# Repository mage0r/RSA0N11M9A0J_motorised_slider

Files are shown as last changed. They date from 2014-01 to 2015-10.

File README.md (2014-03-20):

RSA0N11M9A0J_motorised_slider
=============

This project drives a model RSA0N11M9A0J motorised slider using a common L9110 H-Bridge driver.

It also allows using the built in capacitive sensor to prevent the motor from fighting manual movement.

There has three sections, a kicad circuit diagram, an arduino sketch using the capacitive touch library and lastly a few photos of it in action.

The specifications for the slider are available at (http://www.alps.com/WebObjects/catalog.woa/E/HTML/Potentiometer/SlidePotentiometers/RSN1M/RSA0N11M9A0J.html).  These sliders were salvaged from a Yamaha M7 Audio Mixer (http://www.yamahaproaudio.com/global/en/products/mixers/m7cl/index.jsp) while it was being refurbished.

There are two sketches in the arduino directory.  One for the attiny controller, another one with a basic i2c master for controlling the slaves.  Each sketch includes a list of required libraries.

Improvements and changes cheerfully accepted.

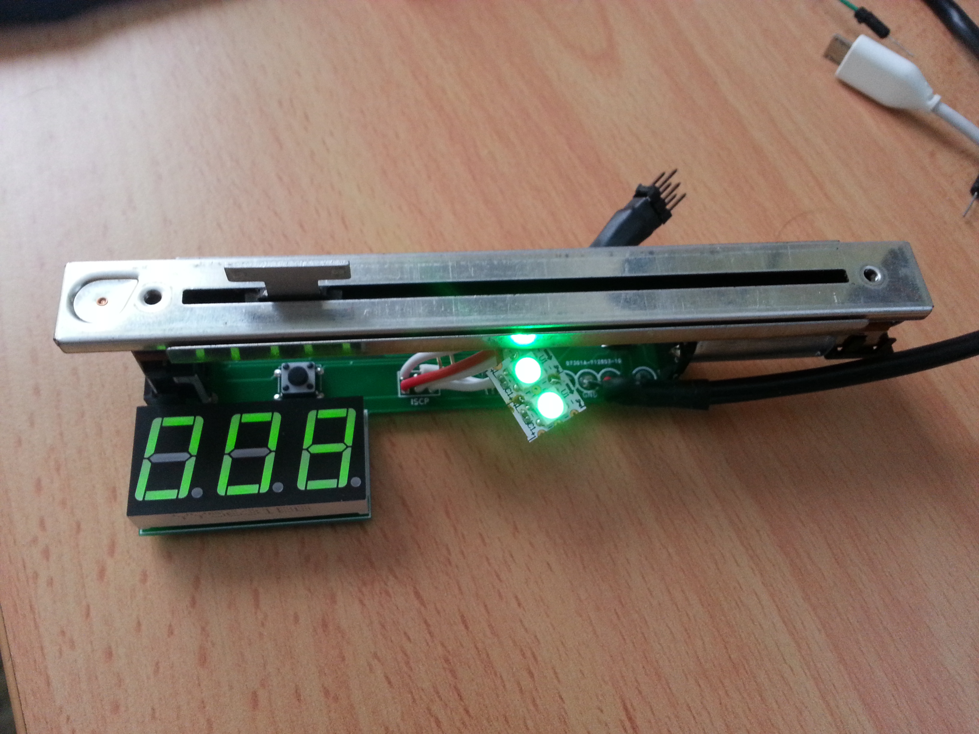
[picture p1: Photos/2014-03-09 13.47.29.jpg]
RSA0N11M9A0J_motorised_slider


(http://youtu.be/SSg5tWOZ5IY "ATtiny Slider Driver - Version 2")

(http://youtu.be/dVUSyDtoAqI "ATtiny 84 Motorised Slider - Version 3 ")

CREDITS
------------
This board was designed by John Spencer - john.spencer.9000@gmail.com - https://github.com/mage0r

SPECIAL THANKS
------------
To the creators and maintainers of the KiCAD open-source EDA suite.

To the HackMelbourne (CCHS, http://hackmelbourne.org) community of Melbourne, Australia.

To all other open-source developers whose countless hours supported every other aspect of this design.

To Andy Gelme for feature creeping an attiny in the design.

Extra thanks to Bob Powers (@rdpowers) because I copied his README.md almost verbatim...

DISTRIBUTION
------------
The specific terms of distribution of this project are governed by the
license referenced below. Please contact the copyright owner if you wish to modify the board for distribution. Please utilize this design for personal or research projects. Please acknowledge all contributors.

LICENSE
-------
Licensed under the TAPR Open Hardware License (www.tapr.org/OHL).
The "license" sub-folder also contains a copy of this license in plain text format.

Copyright John Spencer 2014
john.spencer.9000@gmail.com

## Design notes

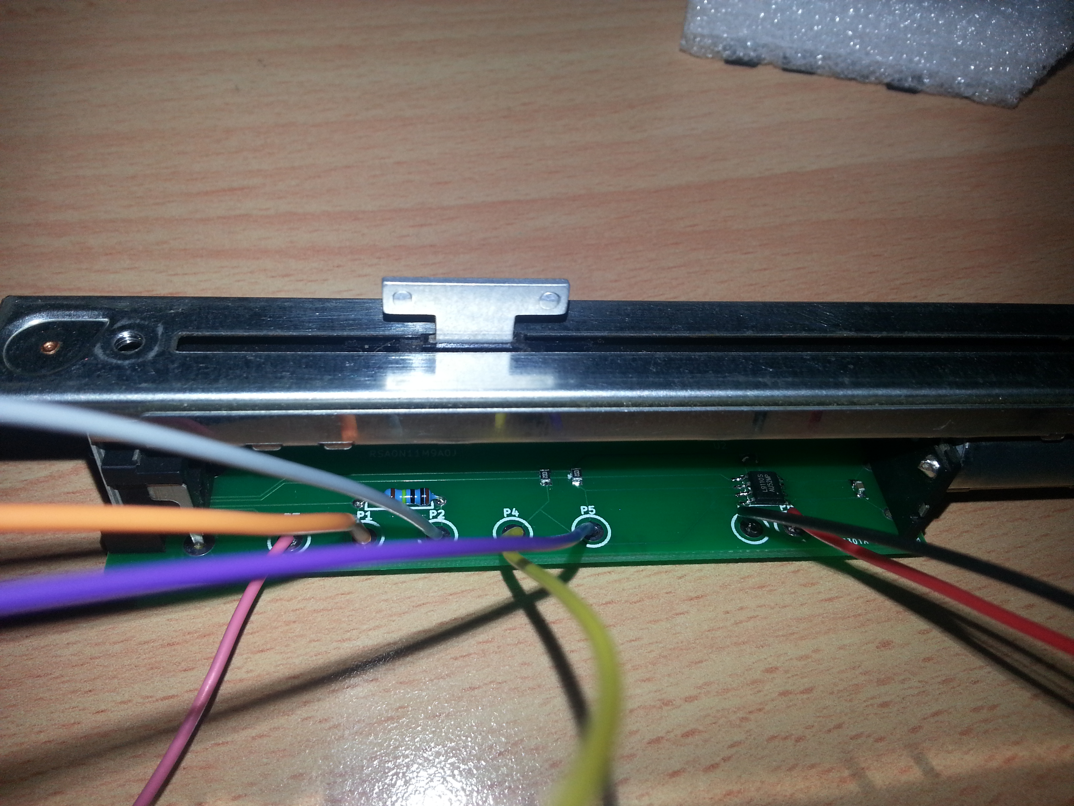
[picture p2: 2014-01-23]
Photos/2014-01-23 20.13.57.jpg

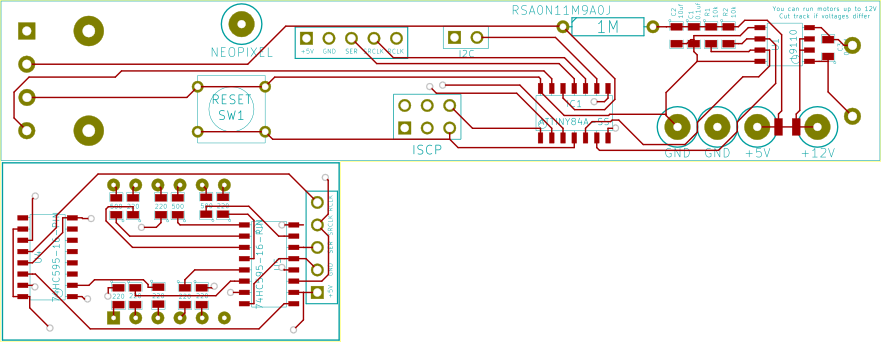
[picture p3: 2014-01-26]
Photos/slider_driver-front.png

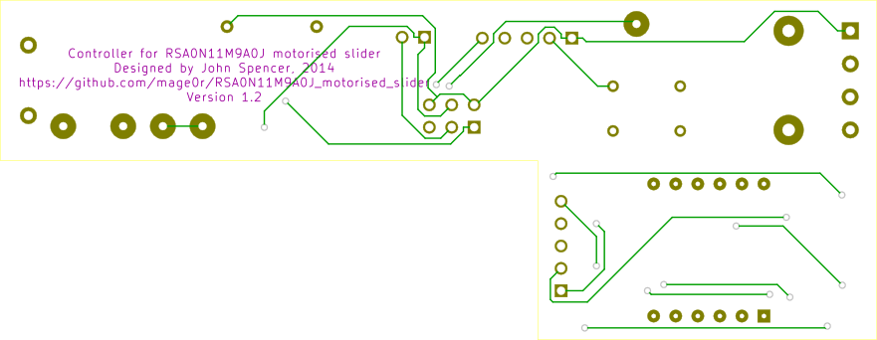
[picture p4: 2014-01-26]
Photos/slider_driver-back.png

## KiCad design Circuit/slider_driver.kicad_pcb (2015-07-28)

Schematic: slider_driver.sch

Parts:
AFF1: 3X7SEGMENTS_1
C1, C3, C4: 0.1uf
C2, C5: 10uf
D1: LED
IC1: ATTINY84A-SS; SO14
K1: Neopixel
K2: PWR
P1, P2: 5_PIN_SOCKET
P3: ISCP
P4: Bridge
R1: 28
R2, R4, R5: 10k
R3: 1M
R15: 1K
U1: MAX7219
U2: RSA0N11M9A0J
U3: L9110

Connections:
+5V: C1.1, C2.1, C4.1, C5.1, IC1.1 (VCC), K1.1, K2.1, P1.1, P2.1, P3.2 (VCC), P4.1, R1.2, R2.1, R4.1, R5.2, R15.1, U1.19 (VCC), U2.1 (+V)
+12V: K2.3, P4.2 (PM), U3.2 (VCC), U3.3 (VCC)
GND: C1.2, C2.2, C4.2, C5.2, D1.2 (K), IC1.14 (GND), K1.3, K2.2 (PM), P1.2, P2.2, P3.6 (GND), U1.4 (GND), U1.9 (GND), U2.3 (GND), U3.5 (GND), U3.8 (GND)
IA: IC1.6 ((PCINT7/ICP/OC0B/ADC7)PA7), R5.1, U3.6 (IA)
IB: IC1.5 ((PCINT10/CKOUT/OC0A/INT0)PB2), R4.2, U3.7 (IB)
MISO: IC1.8 ((PCINT5/DO/MISO/OC1B/ADC5)PA5), P3.1 (MISO), R3.1
MOSI: IC1.7 ((PCINT6/SDA/DI/MOSI/OC1A/ADC6)PA6), P3.4 (MOSI)
Motor_1: C3.2, U2.A (Motor_1), U3.4 (OB)
Motor_2: C3.1, U2.B (Motor_2), U3.1 (OA)
unnamed: P1.5, U1.13 (CLK)
unnamed: R1.1, U1.18 (ISET)
unnamed: AFF1.5, U1.17 (SEG_G)
unnamed: AFF1.7, U1.16 (SEG_B)
unnamed: AFF1.10, U1.15 (SEG_F)
unnamed: AFF1.11, U1.14 (SEG_A)
unnamed: AFF1.2, U1.23 (SEG_D)
unnamed: AFF1.3, U1.22 (SEG_DP)
unnamed: P1.4, U1.12 (LOAD)
unnamed: AFF1.1, U1.21 (SEG_E)
unnamed: AFF1.4, U1.20 (SEG_C)
unnamed: AFF1.12, U1.2 (DIG0)
unnamed: AFF1.9, U1.11 (DIG1)
unnamed: AFF1.8, U1.6 (DIG2)
unnamed: P1.3, U1.1 (DIN)
unnamed: IC1.2 ((PCINT8/CLKI/XTAL1)PB0), K1.2 (PM)
unnamed: D1.1 (A), R15.2
RCLK: IC1.3 ((PCINT9/XTAL2)PB1), P2.5
RESET: IC1.4 ((PCINT11/dW/~RESET~)PB3), P3.5 (RST), R2.2
Receive: IC1.12 ((PCINT1/AIN0/ADC1)PA1), R3.2, U2.T (Touch)
SCK: IC1.9 ((PCINT4/USCK/SCL/T1/ADC4)PA4), P3.3 (SCK)
SER: IC1.11 ((PCINT2/AIN1/ADC2)PA2), P2.3
SRCLK: IC1.10 ((PCINT3/T0/ADC3)PA3), P2.4
Wiper: IC1.13 ((PCINT0/AREF/ADC0)PA0), U2.2 (Wiper)

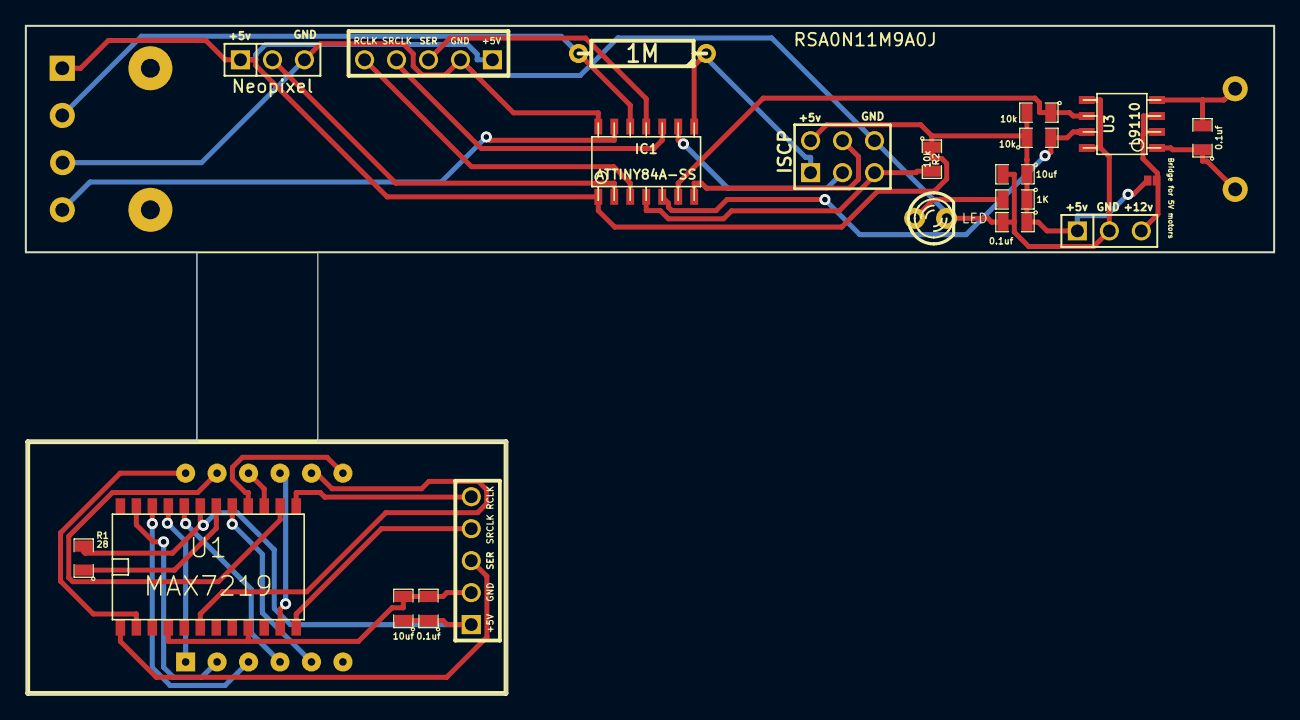
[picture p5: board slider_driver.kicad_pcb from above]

Board: 2 copper layers, 99.2 x 53.1 mm, 23 parts (0 on the bottom side), 33 nets.

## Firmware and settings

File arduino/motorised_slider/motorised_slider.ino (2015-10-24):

/*
  This test code moves a motor based slider up and down using a motor driver.
  John Spencer - 2014
  https://github.com/mage0r/RSA0N11M9A0J_motorised_slider
  
  You'll need the libraries from the following locations.
  https://github.com/adafruit/Adafruit_NeoPixel
  http://playground.arduino.cc/Code/USIi2c
 */
 
 /* To Do
  * ~~~~~
  * - Store / recall I2C address in EEPROM.
  */
 
 #include <CapacitiveSensor.h>
 #include <Adafruit_NeoPixel.h>
 #include "TinyWireS.h"
 
 #include <EEPROM.h>
 
// i2c Address stuff.
#define i2c_eeprom_address 0 // Always gonna be the first bit.

byte i2c_slave_addr;
 
boolean MoveSlider(int moveTo, int currentPosition, int motorIAPin, int motorIBPin, int deadZone, int maxSpeed, int minSpeed );
boolean UpdateDisplay(int number);
void CalibrateCap(int offset);

// Pin variables.
const int capacitivePin = A1; // this is the send pin for capacitive touch
const int motorIAPin = 7;
const int motorIBPin = 8;
const int sensorPin = A0;
const int neopixel = 10;

// serial out for 7 segment
const int clockPin = 3;
const int dataPin = 2; // SER
const int latchPin = 9;

// Cap sense variables.
CapacitiveSensor cap_touch = CapacitiveSensor(5,1);

// movement variables.
unsigned int moveTo; // value to set the slider too.
boolean moveSlider = false; // do we need to move the slider?
unsigned int currentPosition; // previous 3 rolling values.
unsigned long update; // 
unsigned int sliderDeadZone = 10;

// data string input
String inputString = "";
boolean stringComplete = false;

// This is an array of the different digit combinations
const byte digits [11][2] =
{
  {0b00000110,0b00000000}, //0
  {0b00000111,0b11001000}, //1
  {0b00000101,0b00100000}, //2
  {0b00000101,0b10000000}, //3
  {0b00000100,0b11001000}, //4
  {0b00000100,0b10010000}, //5
  {0b00000100,0b00010000}, //6
  {0b00000111,0b11000000}, //7
  {0b00000100,0b00000000}, //8
  {0b00000100,0b11000000}, //9
  {0b00000011,0b11111000}, //.
};

Adafruit_NeoPixel strip = Adafruit_NeoPixel(2, neopixel, NEO_GRB + NEO_KHZ800);

void setup() {
  
  // get i2c address.  If one doesn't exist, set the default.
  i2c_slave_addr = EEPROM.read(i2c_eeprom_address);
  if(!i2c_slave_addr || i2c_slave_addr == 255) { //empty address
    EEPROM.write(i2c_eeprom_address, 38); // we're defaulting to 38
    i2c_slave_addr = 38;
  }
  
  TinyWireS.begin(i2c_slave_addr);
  
  pinMode(dataPin, OUTPUT);
  pinMode(latchPin, OUTPUT);
  pinMode(clockPin, OUTPUT);
  
  pinMode(neopixel, OUTPUT);
  
  update = millis();
  
  // Calibrate the cap sense.
  //cap_touch.set_CS_AutocaL_Millis(0xFFFFFFFF);
  
  // set expected position to current position.
  moveTo = analogRead(sensorPin);
  
  inputString.reserve(50);
  
  strip.begin();
  strip.show();
}

void loop() {

  char inI2C; // i2c temp variable.
  
  if (TinyWireS.available()){           // got I2C input!
  
    inI2C = (char)TinyWireS.receive();     // get the byte from master
    // ; is the end command string.
      if(inI2C != ';'){
        inputString += inI2C;
      }
      else
        stringComplete = true;
  }

  moveTo = 800;
  moveSlider = true;

  // We've received a full command.  Match it to our existing members.
  if(stringComplete) {
    
    if( inputString.charAt(0) == 'M' ){
      // Move the motor to a set position
      moveTo = inputString.substring(1).toInt();
      moveSlider = true;
    }
    else if ( inputString.charAt(0) == 'R' ) {
      i2c_slave_addr = inputString.substring(2,inputString.length()).toInt();
      EEPROM.write(i2c_eeprom_address, i2c_slave_addr);
      TinyWireS.begin(i2c_slave_addr);
    }
    else if ( inputString.charAt(0) == 'U' ) {
      // move the slider up a bit.
      moveTo = moveTo + inputString.substring(1).toInt();
      moveSlider = true;
    }
    else if ( inputString.charAt(0) == 'D' ) {
      // move the slider down a bit.
      moveTo = moveTo - inputString.substring(1).toInt();
      moveSlider = true;
    }
    else if ( inputString.charAt(0) == 'C' ) {
      // re-run the capsense calibration.
      CalibrateCap(inputString.substring(1).toInt());
    }
    else if ( inputString.charAt(0) == 'Z' ) {
      // adjust the deadzone for movement.
      sliderDeadZone = inputString.substring(1).toInt();
    }
    else if( inputString.charAt(0) == 'E' ){
      // Flag error and get user to move to position.
      moveTo = inputString.substring(1).toInt(); 
    }
    else if( inputString.charAt(0) == 'P' ){
      // Request for Position information
      // reuse inputString for output - ugly.
      inputString = "P";
      inputString += String(analogRead(sensorPin));
      inputString += ";";
      char buffer[32];
      inputString.toCharArray(buffer,32);
      for(int i = 0; i < 32; i++) {
        if(buffer[i])
          TinyWireS.send(buffer[i]);
        else
          break;
      }
    }
    else if( inputString.charAt(0) == 'S' ){
      // Request for current settings.
      // Current Position, Dead Zone, CapSense offset and speed offset
      inputString = "P";
      inputString += String(analogRead(sensorPin));
      inputString += ";";
      inputString += "Z";
      inputString += String(sliderDeadZone);
      inputString += ";";
      char buffer[32];
      inputString.toCharArray(buffer,32);
      for(int i = 0; i < 32; i++) {
        if(buffer[i])
          TinyWireS.send(buffer[i]);
        else
          break;
      }
      
    }
    
    // Clear the stream out for the next command.
    inputString = "";
    stringComplete = false;
  }
  
  
  if(currentPosition - analogRead(sensorPin) > sliderDeadZone || analogRead(sensorPin) - currentPosition > sliderDeadZone)
    currentPosition = analogRead(sensorPin);
  
  // Update the display with our current position
  // Currently the display only supports between 0 and 999
  UpdateDisplay(currentPosition);
  
  // Before updating anything, check if we've been touched or not.
  if (cap_touch.capacitiveSensor(5) > baseLine) {
      // On detect, this will resume movement after 5 seconds (hard coded below)
    // update = millis();
    // As an alternative, just stop moving.
    moveSlider = false;
  }
  
  
  if (moveTo-currentPosition < sliderDeadZone || currentPosition-moveTo < sliderDeadZone) {
      // we're where we expect to be!  happy green.
      strip.setPixelColor(0, strip.Color(0, 20, 0));
      strip.setPixelColor(1, strip.Color(0, 20, 0));
  } else if (moveSlider && update < millis()-5000) {
    // We'd like to move, but also check that a timer trigger hasn't happened.
    // At 5v, I find anything less than 150 won't move the sliders
    // do a fresh analogRead here
    moveSlider = MoveSlider(moveTo, analogRead(sensorPin), motorIAPin, motorIBPin, sliderDeadZone, 200, 200);
    
    // Set our colour to be "automation in progress" scheme
    strip.setPixelColor(0, strip.Color(0, 0, 20));
    strip.setPixelColor(1, strip.Color(0, 0, 20));
  } else {
    // We want you to move manually!
      strip.setPixelColor(0, strip.Color(20, 0, 0));
      strip.setPixelColor(1, strip.Color(20, 0, 0));
  }

  // update our colour strip
  strip.show();
}

// update the 7 segment display
// pretty much have to run this each iteration
boolean UpdateDisplay(int displayNumber) {
  
  short ones=0, tens=0, hundreds=0;

  hundreds = int(displayNumber/100);
  
  tens = int((displayNumber%100)/10);
  
  ones = int(displayNumber-(hundreds*100)-(tens*10));
  
  // write 100's
  digitalWrite(latchPin, LOW);
  // Send the value as a binary sequence to the module
  shiftOut(dataPin, clockPin, MSBFIRST, digits[hundreds][0]);
  shiftOut(dataPin, clockPin, MSBFIRST, (digits[hundreds][1]+0b00000100)); // binary addition here sets the segment
  // Enable the latch again to set the output states
  digitalWrite(latchPin, HIGH);
  
  // write 10's
  digitalWrite(latchPin, LOW);
  // Send the value as a binary sequence to the module
  shiftOut(dataPin, clockPin, MSBFIRST, digits[tens][0]);
  shiftOut(dataPin, clockPin, MSBFIRST, (digits[tens][1]+0b00000010)); // binary addition here sets the segment
  // Enable the latch again to set the output states
  digitalWrite(latchPin, HIGH);
  
  // write 1's
  digitalWrite(latchPin, LOW);
  // Send the value as a binary sequence to the module
  shiftOut(dataPin, clockPin, MSBFIRST, digits[ones][0]);
  shiftOut(dataPin, clockPin, MSBFIRST, (digits[ones][1]+0b00000001)); // binary addition here sets the segment
  // Enable the latch again to set the output states
  digitalWrite(latchPin, HIGH);
  
  // switch off.  Keeps the LED's at a consistent brightness.
  digitalWrite(latchPin, LOW);
  // Send the value as a binary sequence to the module
  shiftOut(dataPin, clockPin, MSBFIRST, 0b00000111);
  shiftOut(dataPin, clockPin, MSBFIRST, 0b11111000); // binary addition here sets the segment
  // Enable the latch again to set the output states
  digitalWrite(latchPin, HIGH);
  
  return true; 
}

// This method moves the slider to requested position.
// It handles acceleration and dead zone to prevent bouncing.
boolean MoveSlider(int moveTo, int currentPosition, int motorIAPin, int motorIBPin, int deadZone = 10, int maxSpeed = 255, int minSpeed = 200) {
  // hacky while I work out how to do this.
  int motorSpeed = maxSpeed;

  // lets cheat a bit to do the deadzone stuff.
  moveTo = map(moveTo, 1, 1023, 0, 1024/deadZone);
  currentPosition = map(currentPosition, 1, 1023, 0, 1024/deadZone);
  
    if ( moveTo < currentPosition ){
      if ( ( currentPosition - moveTo ) < 2*deadZone )
        motorSpeed = minSpeed;
      analogWrite(motorIAPin, LOW);
      analogWrite(motorIBPin, motorSpeed);
    }
    else if ( moveTo > currentPosition ){
      if ( (moveTo - currentPosition ) < 2*deadZone )
        motorSpeed = minSpeed;
      analogWrite(motorIAPin, motorSpeed);
      analogWrite(motorIBPin, LOW);
    }
    else {
        digitalWrite(motorIAPin, LOW);
        digitalWrite(motorIBPin, LOW);
        //Serial.println("slider disengadged.");
        return false;
    }
    
    return true; 
}

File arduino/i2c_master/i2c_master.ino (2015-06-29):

/*

  Control menu for I2C motorised slider control
  John Spencer - 2014
  https://github.com/mage0r/RSA0N11M9A0J_motorised_slider
  
  Adapted from:
  http://www.forkrobotics.com/2012/05/relay-control-over-i2c/
  
  
  
*/

#include <Wire.h>
byte ATtinyAddress=0x26;

String inputString = "";         // a string to hold incoming data
boolean stringComplete = false;  // whether the string is complete
String receiveString = "";
boolean receiveComplete = false;

void setup(){
    Wire.begin();
    Serial.begin(9600);
    inputString.reserve(200);
    findDevices();
    PrintMenu();
    
}
void loop(){
  
  char inSerial; // temporary serial character
  char inWire;
  
  if(Serial.available()){
     inSerial = (char)Serial.read();
     
       inputString += inSerial;
     
     if (inSerial == ';')
       stringComplete = true;
   }
   
   if (stringComplete) {
     if ( inputString.charAt(0) == 'A' ) {
       ATtinyAddress = inputString.substring(1,inputString.length()-1).toInt();
       Serial.print("Writing to device: 0x");
       Serial.println(ATtinyAddress,HEX);
     }
     else if ( inputString.charAt(0) == 'F' ) {
       findDevices();
     }
     else
     {
       SendI2C(ATtinyAddress,inputString);
     }
     
     inputString = "";
     stringComplete = false;
   }
   
   if (Wire.available()) {
     inWire = (char)Wire.read();
     
       receiveString += inWire;
     
     if (inWire == ';')
       receiveComplete = true;
   }
   
   if (receiveComplete) {
     Serial.println(receiveString);
   }
  
}

void PrintMenu(){
  Serial.println("--- Relay Menu ---");
  Serial.println("e.g. M800; // move to 800");
  Serial.println("e.g. E800; // get user to move to 800");
  Serial.println("e.g. U10; // move up 10");
  Serial.println("e.g. D10; // move down 10 ");
  Serial.println("e.g. C20; // recalibrate capsense with offset 20");
  Serial.println("e.g. Z10; // deadzone is now 10");
  Serial.println("e.g. A38; // i2c address 38 (0x26)");
}

void SendI2C(byte device,String data) {
  
  char buffer[32];
  Wire.beginTransmission(device);
  data.toCharArray(buffer,32);
  Wire.write(buffer);
  Wire.endTransmission();
}

void findDevices()
{
  byte error, address;

  Serial.println("Scanning for i2c devices...");

  for(address = 1; address < 127; address++ ) 
  {
    // The i2c_scanner uses the return value of
    // the Write.endTransmisstion to see if
    // a device did acknowledge to the address.
    Wire.beginTransmission(address);
    error = Wire.endTransmission();

    if (error == 0)
    {
      Serial.print("I2C device found at address 0x");
      if (address<16) 
        Serial.print("0");
      Serial.print(address,HEX);
      Serial.println("  !");
    }
  }
  Serial.println("Done Scanning.");
}

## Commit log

2014-01-23 Added arduino code
2014-01-23 kicad files uploaded
    [slider_driver.dsn, slider_driver.kicad_pcb, slider_driver.sch]
2014-01-26 added attiny to board
    Bit of a feature creep here. The board is now it's own little self
    contained unit that can be accessed using i2c.
    [slider_driver.dsn, slider_driver.kicad_pcb, slider_driver.sch]
2014-01-26 added png's of the board
    [slider_driver.kicad_pcb]
2014-02-25 changed directory structure
    [slider_driver-B_Cu.gbl, slider_driver-B_Mask.gbs, slider_driver-B_SilkS.gbo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]
2014-03-02 fixed pin for iscp port
    Total screw up there.
    [slider_driver.dsn, slider_driver.kicad_pcb, slider_driver.sch]
2014-03-08 experimental motorslider
    [slider_driver.kicad_pcb]
2014-03-12 Extra pins Re Bug #3
    [slider_driver.dsn, slider_driver.kicad_pcb, slider_driver.sch]
2014-03-15 typo in i2c pin name
2014-03-19 i2c support added into arduino
    No idea what I changed in the pcb :)
    [slider_driver.kicad_pcb]
2014-04-03 These files aren't meant to be there....
    They're all out of date anyway.
    [slider_driver-B_Cu.gbl, slider_driver-B_Mask.gbs, slider_driver-B_SilkS.gbo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]
2014-04-03 ignoring gerbers and zips
2015-06-29 Updated board
2015-06-29 Updated board to support max chip
    [slider_driver.dsn, slider_driver.kicad_pcb, slider_driver.sch]
2015-07-28 Adaption to make fab people happy.
    [slider_driver.kicad_pcb]
2016-09-08 Some changes that I guess were important at some point
    [slider_driver.sch]
